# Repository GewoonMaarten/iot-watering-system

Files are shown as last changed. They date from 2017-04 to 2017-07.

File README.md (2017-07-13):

# IOT watering system 
Watering system with moisture sensor and firebase database.

## Firebase 
This project uses Firebase from Google to store the data collected from the moisture sensor. The Arduino code only uploads the value from the moisture sensor and whether the pump is on to the database. There is a Nodejs project include which, when uploaded as a cloud function to the Firebase database will add a datetime to the newly added values. Another function is added to clean the measurements that are older than one month. This data is not valuable to me so remove it.

### The JSON structure
The cloud function will format a datetime based on the machine time. the format is a YYYY-MM-DD HH:mm:ss, e.g.: `2017-04-13 16:59:23`.
The Arduino codes add a boolean based on whether the pump is currently active. And the value the value of the moisture sensor is added.
This all combined gives the following data structure: 
``` JSON
{
  "measurement" : {
    "-KgQiGUIjxPrxezXVW1H" : {
      "dateTime" : "2017-04-13 16:59:23",
      "isWatering" : 0,
      "value" : 2.72
    }
  }
} 
```

## The Hardware
### Parts list:
I bought most of the things on Ali Express so thats where I will provide links for.
* [WEmos D1 mini](https://www.aliexpress.com/item/D1-mini-V2-Mini-NodeMcu-4M-bytes-Lua-WIFI-Internet-of-Things-development-board-based-ESP8266/32529101036.html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)
* [Power Relay (5v)](https://www.aliexpress.com/item/10PCS-RELAY-5V-SRD-5VDC-SL-C-T73-5V-Power-Relay-NEW/32444246523.html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)
* [Small pump](https://www.aliexpress.com/item/1Pcs-DC-12v-D2-Small-Dosing-Pump-2mm-DIY-Peristaltic-Tube-Head-For-Aquarium-Lab-Chemical/32650282709.html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)
* [Tube](https://www.aliexpress.com/item/3M-2-4mm-2x4mm-Creamy-White-Black-Red-Yellow-Medical-Food-Grade-Drink-Machine-Flexible-Pipe/32787873264.html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)
* [Moisture sensor](https://www.aliexpress.com/item/1Pcs-Soil-Hygrometer-Detection-Module-Soil-Moisture-Sensor/2035877568.html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)
* A way to convert 12v to 5v. Is used [this](https://www.aliexpress.com/item/8pcs-10W-Breadboard-Power-Module-DC-6-5V-23V-12V-to-5V-DC-DC-Converter-replace/32326359914.html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). But you could use a 5v regulator.
* Diode
* NPN transistor. I used a BC547
* Wire
* 12v powersupply with 5.5 * 2.1mm DC jack

#### Schematic:
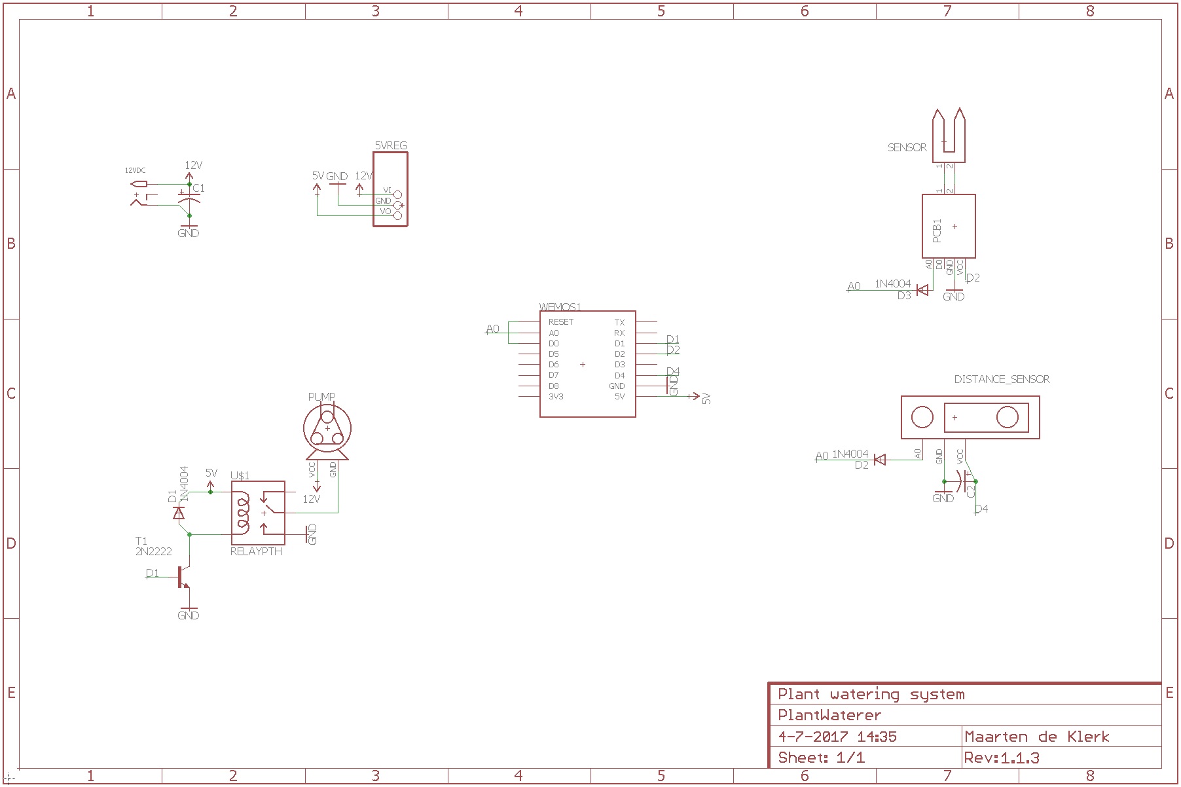
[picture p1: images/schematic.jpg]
Schematic


#### PCB:
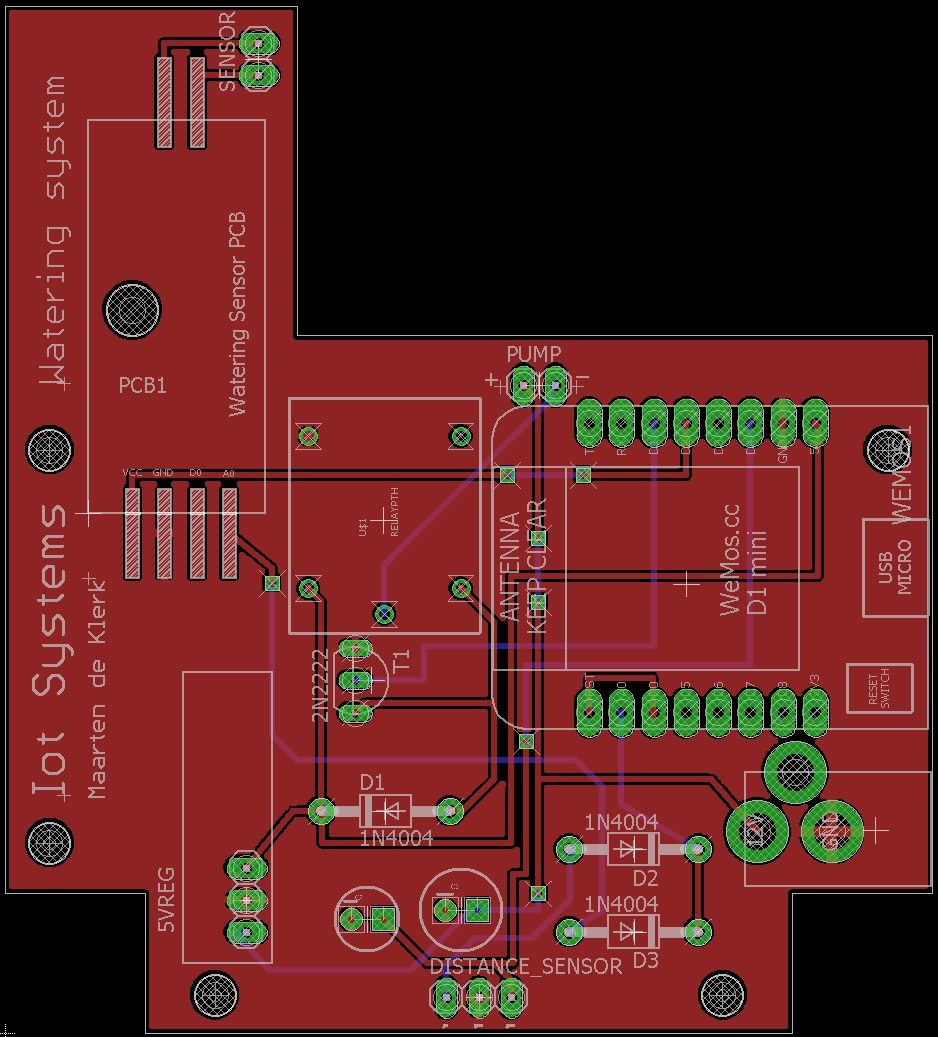
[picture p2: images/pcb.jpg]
pcb


The final product: <br />


#### Related
How to plot the sensor data:
[Systems.maartens.website](http://maartens.website/)

License: [MIT](https://github.com/GewoonMaarten/iot-watering-system/blob/master/LICENSE)

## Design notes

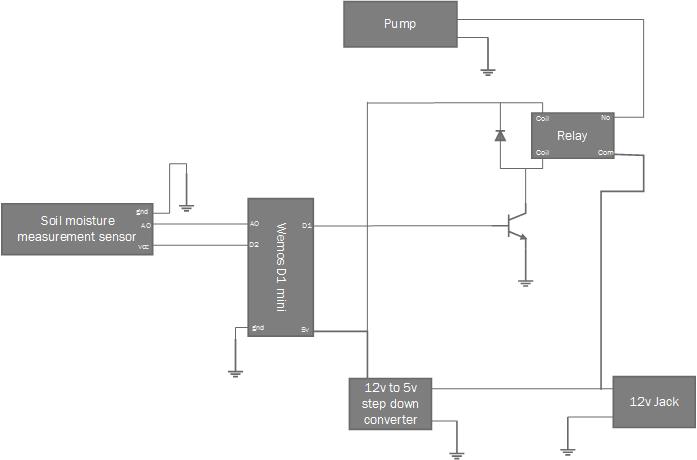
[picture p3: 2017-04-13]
images/layout schematic.jpg

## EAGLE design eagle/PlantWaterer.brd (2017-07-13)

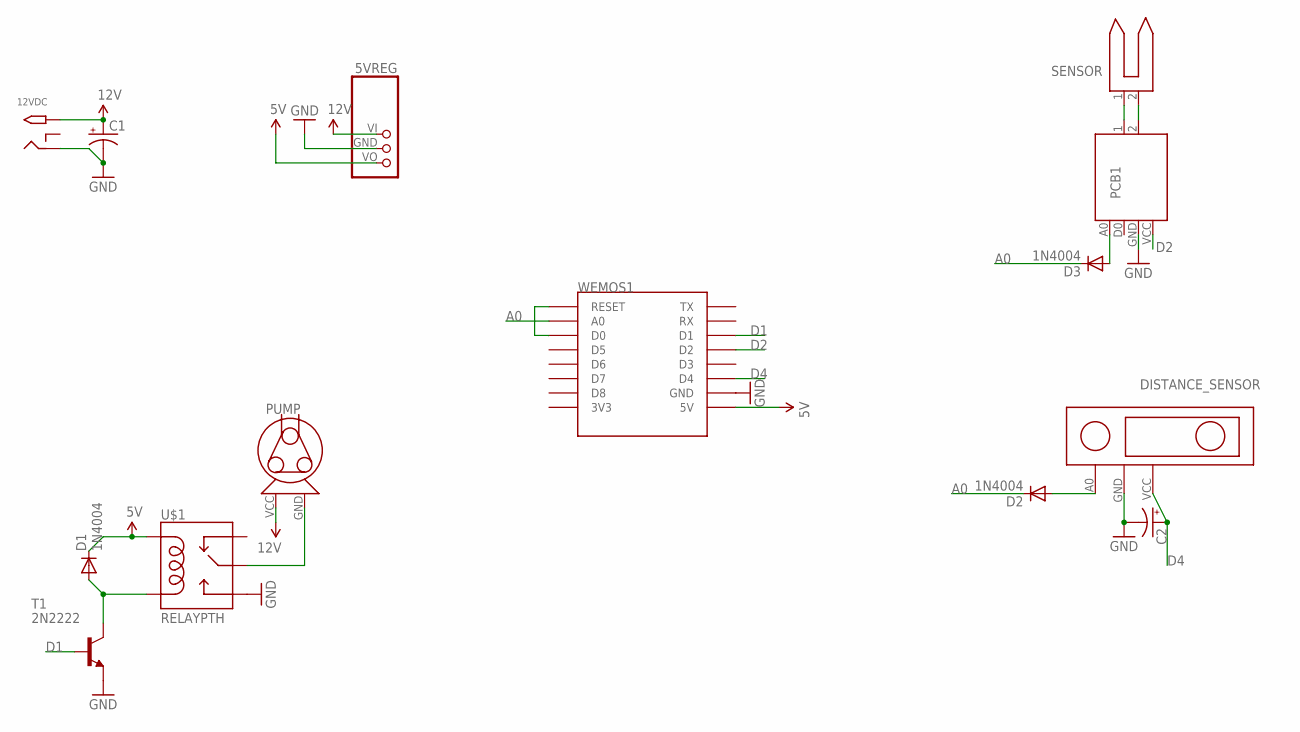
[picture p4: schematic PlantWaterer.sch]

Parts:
5VREG: 5V_REG
12VDC: 2.1MMJACK; PJ-102A
C1: 100UF-25V-20%(PTH); CPOL-RADIAL-100UF-25V
C2: 10UF-25V-20%(PTH); CPOL-RADIAL-10UF-25V
D1, D2, D3: 1N4004; DO41-10
DISTANCE_SENSOR: SHARP_GP2Y0A21YK
PCB1: WATER_SENSOR_PCB
PUMP: PERISTALTIC_PUMP
SENSOR: WATER_SENSOR
T1: 2N2222; TO92-EBC-OVAL
U$1: RELAYPTH; SRD-05VDC-SL-C
WEMOS1: WEMOS-D1-MINI

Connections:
5V: 5VREG.VO, D1.C, U$1.COIL1, WEMOS1.5V
12V: 5VREG.VI, 12VDC.TIP, C1.1 (+), PUMP.VCC
A0: D2.C, D3.C, WEMOS1.A0
D1: T1.B, WEMOS1.D1
D2: PCB1.VCC, WEMOS1.D2
D4: C2.1 (+), DISTANCE_SENSOR.VCC, WEMOS1.D4
GND: 5VREG.GND, 12VDC.RING, C1.2 (-), C2.2 (-), DISTANCE_SENSOR.GND, PCB1.GND, T1.E, U$1.SWOPEN, WEMOS1.GND
unnamed: D1.A, T1.C, U$1.COIL0
unnamed: D2.A, DISTANCE_SENSOR.A0
unnamed: WEMOS1.D0, WEMOS1.RESET
unnamed: PUMP.GND, U$1.SWCOMMON
unnamed: PCB1.1, SENSOR.1
unnamed: PCB1.2, SENSOR.2
unnamed: D3.A, PCB1.A0

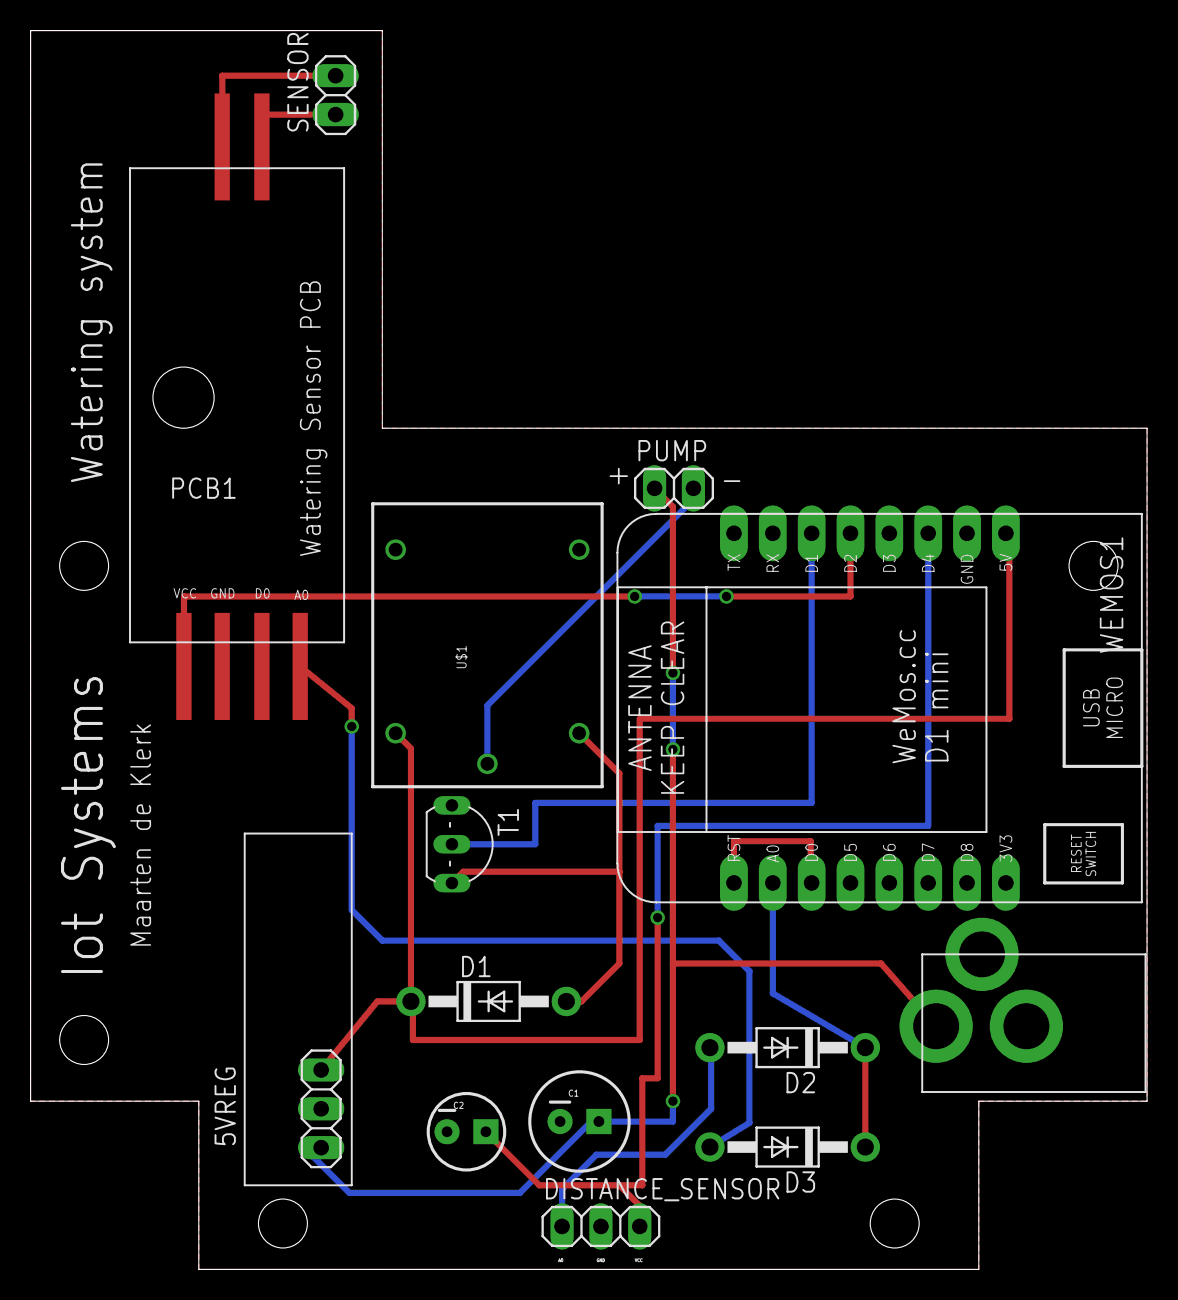
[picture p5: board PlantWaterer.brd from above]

Board: 2 copper layers, 73.0 x 81.0 mm, 14 parts (0 on the bottom side), 14 nets.

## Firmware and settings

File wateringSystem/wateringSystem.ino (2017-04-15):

#include <Firebase.h>
#include <FirebaseArduino.h>
#include <FirebaseCloudMessaging.h>
#include <FirebaseError.h>
#include <FirebaseHttpClient.h>
#include <FirebaseObject.h>

#include <ESP8266WiFi.h>

#include <ArduinoOTA.h>

// All passwords and urls
#include "configuration.h"

int relayPin = 5;
int sensorVCCPin = 4;
int whatToFlash = 0;

void setup() {
  Serial.begin(115200);
  Serial.println();

  pinMode(relayPin, OUTPUT);
  pinMode(sensorVCCPin, OUTPUT);

  digitalWrite(relayPin, LOW);
  digitalWrite(sensorVCCPin, LOW);
  
  //Connect to wifi
  WiFi.begin(ssid, ssid_password);
  Serial.print("connecting");
  while (WiFi.status() != WL_CONNECTED){
    Serial.print(".");
    delay(500);
  }
  Serial.println(WiFi.localIP());


  ArduinoOTA.begin();
  ArduinoOTA.setPort(3000);
  ArduinoOTA.setHostname((char*) "water-system-0");
  ArduinoOTA.setPassword((char*) ota_password);

  Firebase.begin(firebase_url, firebase_auth);

  ArduinoOTA.onStart([]() {
    Firebase.setInt("devices/1/watering-system-0/readyToFlash", 0);
  });

  whatToFlash = Firebase.getInt("devices/1/watering-system-0/whatToFlash");
}

void uploadValue(){
  float value = readSensor();
  boolean isWatering = powerPump(value);
  
  StaticJsonBuffer<200> jsonBuffer;
  JsonObject& root = jsonBuffer.createObject(); 
  root["value"] = double_with_n_digits(value, 2);
  root["isWatering"] = isWatering;
  
  root.prettyPrintTo(Serial);
  Firebase.push("devices/1/watering-system-0/measurements", root);
  if(Firebase.failed()){
    Serial.print("setting /truth failed:");
    Serial.println(Firebase.error());
    return;
  }
  Serial.println("Going into deep sleep");
  
  // Sleep for an 1 hour
  ESP.deepSleep(3600000000, WAKE_RF_DEFAULT);
  delay(100);
}

float readSensor(){
  digitalWrite(sensorVCCPin, HIGH);
  delay(1000);
  int sensorValue = analogRead(A0);
  float voltage = sensorValue * (3.2 / 1023.0);
  digitalWrite(sensorVCCPin, LOW);
  return voltage;
}

boolean powerPump(float value){
  if(value > 2.90){
    digitalWrite(relayPin, HIGH);
    Serial.println("Relay high");
    delay(10000);
    return true;
  } else {
    digitalWrite(relayPin, LOW);
    Serial.println("Relay low");
    return false;
  }
}
void loop(){
  if(whatToFlash == 1){
    Firebase.setInt("devices/1/watering-system-0/readyToFlash", 1);
    ArduinoOTA.handle();
  } else {
    Firebase.setInt("devices/1/watering-system-0/readyToFlash", 0);
    uploadValue();
  }
}

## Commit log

2017-03-30 Updated schematic
2017-04-03 Updated schematics
2017-04-07 Picutre of final board
2017-04-13 Added image, fixed typo and fixed schematic
2017-07-13 Added pcb layout
    [PlantWaterer.brd, PlantWaterer.sch]

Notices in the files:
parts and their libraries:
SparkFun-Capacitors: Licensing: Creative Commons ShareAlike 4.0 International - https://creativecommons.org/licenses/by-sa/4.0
